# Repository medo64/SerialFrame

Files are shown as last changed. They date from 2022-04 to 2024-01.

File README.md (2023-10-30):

[Isolated UART Framework Expansion Card](https://medo64.com/uartisowork/)
=========================================================================

This Framework laptop expansion card will show up on your system as a serial
device and allow for a fully isolated serial UART communication up to 1 Mbaud
rate.

Please note that this card is not using RS-232 but TTL (either 3.3V or 5V)
voltage levels (depending on the solder-jumper position).

## UART Pinout

To connect to this board, one has to use 3-pin JST XH connector. The following
table represents the pinout, pin 1 being on the left as looking into the
expansion card.

| # | Ref | Description |
|--:|:---:|---|
| 1 | RXD | Receive (TTL: 5V or 3.3V) |
| 2 | GND | Ground connection |
| 3 | TXD | Transmit (TTL: 5V or 3.3V) |

PPS: As power consumption is below 10 mA, wires can be almost any AWG. I would
recommend using 24 AWG wire (0.25 mm²) as they allow for greater compatibility
with other connectors.

## Supported Speeds

This board employs the FT232R as its UART chip, and consequently, it supports
all the baud rates this chip [can handle](https://ftdichip.com/Documents/AppNotes/AN232B-05_BaudRates.pdf)
up to 1 Mbaud which is the limit of isolator chip used. The table below lists
the standard baud rates.

| Baud rate | Actual | Error | Divisor |
|---:|---:|---:|---:|
| 300 | 300 | 0.00% |  10000.000 |
| 600 | 600 | 0.00% | 5000.000 |
| 1,200 | 1,200 | 0.00% | 2500.000 |
| 1,800 | 1,800 | 0.00% | 1666.625 |
| 2,400 | 2,400 | 0.00% | 1250.000 |
| 4,800 | 4,800 | 0.00% | 625.000 |
| 7,200 | 7,201 | 0.01% | 416.625 |
| 9,600 | 9,600 | 0.00% | 312.500 |
| 14,400 | 14,406 | 0.04% | 208.250 |
| 19,200 | 19,200 | 0.00% | 156.250 |
| 28,800 | 28,812 | 0.04% | 104.125 |
| 38,400 | 38,400 | 0.00% | 78.125 |
| 57,600 | 57,692 | 0.16% | 52.000 |
| 115,200 | 115,385 | 0.16% | 26.000 |
| 230,400 | 230,769 | 0.16% | 13.000 |
| 460,800 | 461,538 | 0.16% | 6.500 |
| 921,600 | 923,077 | 0.16% | 3.250 |

---
*You can check my blog and other projects at [www.medo64.com](https://www.medo64.com/electronics/).*

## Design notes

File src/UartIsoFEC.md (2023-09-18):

### UartIsoFEC Parts

|  # | Part | RefDes  | Preferred Part Number |
|---:|---|---|---|
|  2 | C 47pF NP0 16V (0805) | C1-C2 | 399-C0805C470J5GAC7800CT-ND |
|  1 | C 10nF X7R 16V (0805) | C3 | 399-17617-1-ND |
|  7 | C 100nF X7R 16V (0805) | C4-C10  | 478-5311-1-ND |
|  1 | C 4.7uF X5R 16V (0805) | C11 | 1276-1244-1-ND |
|  2 | C 10uF X5R 16V (0805) | C12-C13 | 1276-1096-1-ND |
|  1 | D TVS 5V SM05T1G (SOT23-3) | D1 | SM05T1GOSCT-ND |
|  2 | DS LED (0805) | DS1-DS2 | 475-1415-1-ND |
|  1 | J JST XH Vertical (3w) | J1 | 455-2248-ND |
|  1 | L Ferrite 600R@100Mhz | L1 | 240-2390-1-ND |
|  1 | Q P-MOSFET DMP3099L-13 (SOT23) | Q1 | DMP3099L-13DICT-ND |
|  2 | R 27 1% (0805) | R1-R2 | 738-RMCF0805FT27R0CT-ND |
|  3 | R 1K 0.125W (0805) | R3-R5 | RMCF0805FT1K00CT-ND |
|  1 | R 5.1K 0.125W (0805) | R6 | RMCF0805FT5K10CT-ND |
|  1 | R 10K 0.125W (0805) | R7 | RMCF0805FT10K0CT-ND |
|  1 | R 16.9K 0.125W (0805) | R8 | RMCF0805FT16K9CT-ND |
|  1 | R 30.9K 0.125W (0805) | R9 | RMCF0805FT30K9CT-ND |
|  1 | R 100K 0.125W (0805) | R10 | RMCF0805FT100KCT-ND |
|  1 | U Transciever Uart FT230XS (SSOP-16) | U1 | 768-1154-5-ND |
|  1 | U Isolator+Power 1Mbps 2ch ADUM5211ARSZ (SSOP-20) | U2 | 505-ADUM5211ARSZ-ND |

#### Board Size

| | Dimensions | Area | Thickness |
|---|---|---|---|
| PCB |  24.0 x 27.9 mm | 1.1 in² | 0.8 mm |

#### FTDI Configuration

| Setting | Value  |
|---|---|
| CBUS0 | TXDEN  |
| CBUS1 | RXLED# |
| CBUS2 | TXLED# |
| CBUS3 | PWREN# |

#### Power

| Property | Value  |
|---|---:|
| Voltage  | 5 V |
| Current  | 100 mA |

#### Jumpers

##### 3V3

This jumper has to be bridged for operation in 3.3V. If this jumper is bridged,
5V jumper MUST NOT be bridged too.

##### 5V

This jumper has to be bridged for operation in 5V. If this jumper is bridged,
3.3V jumper MUST NOT be bridged too.

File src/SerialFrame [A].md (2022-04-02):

### SerialFrame Parts

|  # | Part | RefDes  | Preferred Part Number |
|---:|---|---|---|
|  3 | C 100nF X7R 16V (0805) | C1-C3 | 478-5311-1-ND |
|  1 | C 470nF X7R 16V (0805) | C4 | 1276-1199-1-ND |
|  2 | C 10uF X5R 16V (0805) | C5-C6 | 1276-1096-1-ND |
|  2 | DS LED (0805) | DS1-DS2 | 475-1415-1-ND |
|  1 | J JST PH Vertical (5w) | J1 | 455-1707-ND |
|  1 | P USB C, plug, straddle 0.8mm | P1 | WM12855-ND |
|  1 | Q P-MOSFET DMP3099L-13 (SOT23) | Q1 | DMP3099L-13DICT-ND |
|  2 | R 1K 0.125W (0805) | R1-R2 | RMCF0805FT1K00CT-ND |
|  2 | R 5.1K 0.125W (0805) | R3-R4 | RMCF0805FT5K10CT-ND |
|  1 | U MCP2221A (SOIC-14) | U1 | MCP2221A-I/SL-ND |
|  1 | U SI8421AB-D-IS (SOIC-8) | U2 | 336-1755-5-ND |

#### Board Size

| | Dimensions | Area | Thickness |
|---|---|---|---|
| PCB |  24.0 x 27.9 mm | 1.1 in² | 0.8 mm |

#### Power

| Property | Value  |
|---|---:|
| Voltage  | 5 V |
| Current  | 100 mA |

##### Non-Insulated Interface

If one doesn't need insulation (or you really hate your laptop), you can convert
the card into a non-insulated serial interface by soldering 0 Ω resistor on the
bottom (normally unpopulated) and omiting the following components:
* C2, C3
* C5, C6
* DS2
* Q1
* R2
* U2

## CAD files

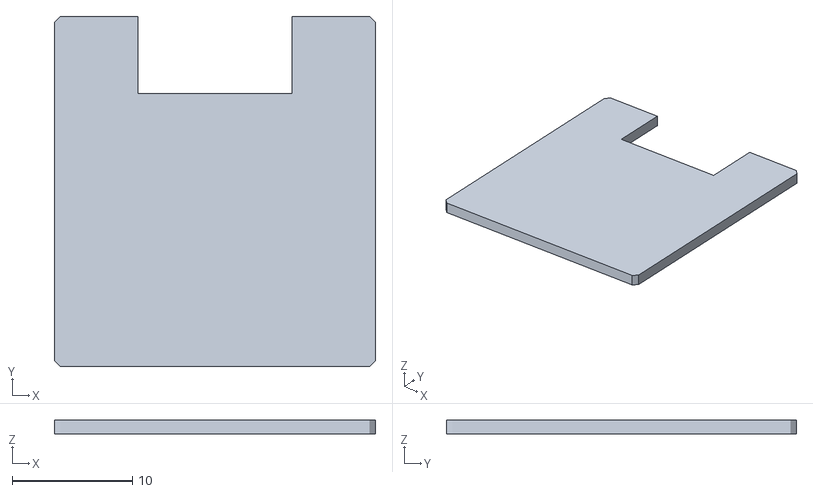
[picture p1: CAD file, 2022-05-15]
src/UartIsoFEC Case Top.stl
26.7 x 29.1 x 1.20

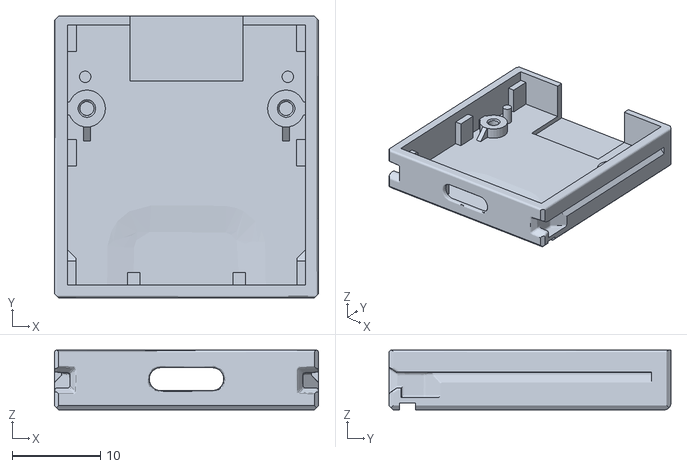
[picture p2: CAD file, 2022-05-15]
src/UartIsoFEC Case Base.stl
30.0 x 32.0 x 6.80

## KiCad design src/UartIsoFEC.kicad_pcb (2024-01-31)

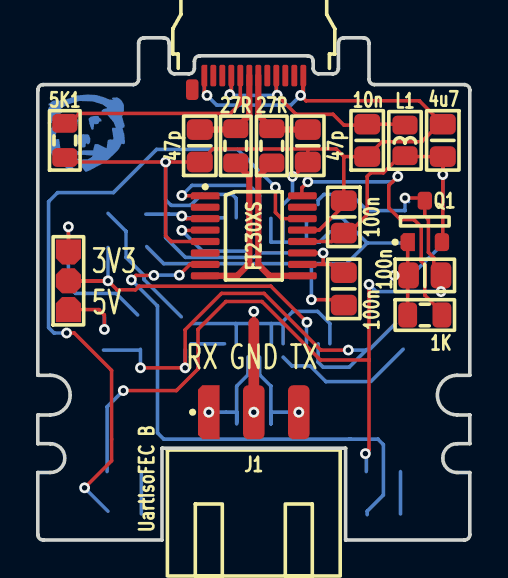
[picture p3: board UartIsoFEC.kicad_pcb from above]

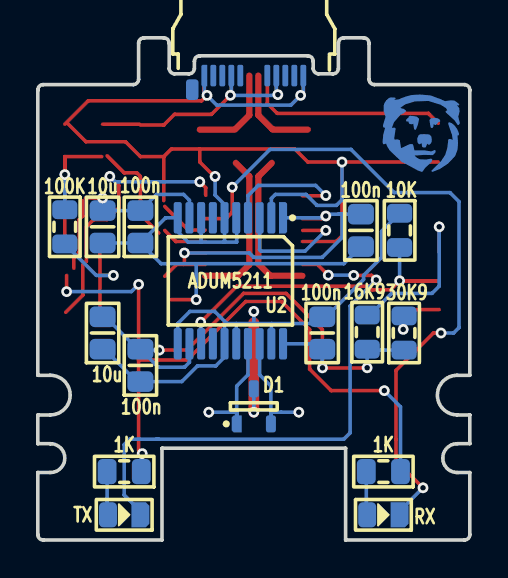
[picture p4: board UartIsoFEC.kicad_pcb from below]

Board: 2 copper layers, 24.0 x 27.9 mm, 34 parts (17 on the bottom side), 25 nets.

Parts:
C1, C2: 47p; C (0805)
C3: 10n; C (0805)
C4, C5, C6, C7, C8, C9, C10: 100n; C (0805)
C11: 4u7; C (0805)
C12, C13: 10u; C (0805)
D1: SM05T1G; D TVS SM05T1G (SOT23-3)
DS1: RX; DS (0805)
DS2: TX; DS (0805)
ICON: Medo64; ICON Medo64
J1: B3B-XH-A; J JST XH Edge [UART] (3w)
JP1: Jumper; JP Dual (1205)
L1: 600R; L (0805)
P1: 105444-0001; P USB C 3.2 Edge (24w)
Q1: DMP3099L-13; Q MOSFET-P (SOT23-3)
R1, R2: 27R; R (0805)
R3, R4, R5: 1K; R (0805)
R6: 5K1; R (0805)
R7: 10K; R (0805)
R8: 16K9; R (0805)
R9: 30K9; R (0805)
R10: 100K; R (0805)
U1: FT230XS; U Transciever UART FT230XS (SSOP-16)
U2: ADUM5211; U Isolator+Power ADUM5211ARSZ (SSOP-20)

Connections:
3V3: C5.2, C8.2, U1.3, U1.10, U1.11, U2.1
5V: C4.2, C11.2, L1.1, Q1.2, R10.1, U1.12
5V_SWITCHED: C6.2, C7.2, C12.2, Q1.3, R3.1, R4.1, U2.9
GND: C1.1, C2.1, C3.1, C4.1, C5.1, C7.1, C8.1, C11.1, C12.1, P1.A1, P1.A12, P1.B01, P1.B12, R6.1, U1.5, U1.13, U2.2, U2.5, U2.6, U2.8, U2.10
ISO_GND: C9.1, C10.1, C13.1, D1.3, J1.2, R7.1, U2.11, U2.15, U2.16, U2.19
ISO_RX: D1.2, J1.1, U2.18
ISO_TX: D1.1, J1.3, U2.17
ISO_V+: C9.2, C10.2, C13.2, R8.1, R9.1, U2.12, U2.20
ISO_V_SELECT: JP1.2, R7.2, U2.13
ISO_V_SELECT_3V3: JP1.3, R8.2
ISO_V_SELECT_5V: JP1.1, R9.2
LED_RX: DS1.1, U1.14
LED_RX': DS1.2, R3.2
LED_TX: DS2.1, U1.7
LED_TX': DS2.2, R4.2
PWREN#: R5.2, U1.16
PWREN#': C6.1, Q1.1, R5.1, R10.2
RX: U1.4, U2.3
TX: U1.1, U2.4
USB_CC: P1.A5, R6.2
USB_DM: C2.2, P1.A7, R2.2
USB_DM': R2.1, U1.9
USB_DP: C1.2, P1.A6, R1.2
USB_DP': R1.1, U1.8
USB_V+: C3.2, L1.2, P1.A4, P1.A9, P1.B04, P1.B09

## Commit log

2022-04-02 Added reverse voltage protection diode
2022-04-02 LED on by default
2022-04-02 Using MOSFET for reverse protection
2022-04-02 Updated MOSFET
2022-04-02 Added wiring text file
2022-04-18 Moving LEDs a bit
2022-05-07 Removed extra CC2 resistor
2022-05-09 Changed connector to XH variant
2022-05-09 Added case STLs
    [UartIsoWork [A] CaseBase.stl, UartIsoWork [A] CaseTop.stl]
2022-05-15 Updated case STLs
    [UartIsoWork [A] CaseBase.stl, UartIsoWork [A] CaseTop.stl]
2023-09-17 Initial layout
    [UartIsoFEC.kicad_pcb]
2023-09-18 New revision using FT260X
    [UartIsoFEC Case Base.stl, UartIsoFEC Case Top.stl, UartIsoFEC.kicad_pcb]
2023-09-18 Added protection diode
    [UartIsoFEC.kicad_pcb]
2023-10-10 Larger silkscreen markings
    [UartIsoFEC.kicad_pcb]
2023-10-25 Updated footprints
    [UartIsoFEC.kicad_pcb]
2023-10-30 Rotated CC resistor
    [UartIsoFEC.kicad_pcb]
2023-10-30 Increased drive current
2023-11-03 Updated net names
    [UartIsoFEC.kicad_pcb]
2023-11-04 Added RTS/CTS loopback
    [UartIsoFEC.kicad_pcb]
2023-11-13 Moved LEDs to bottom
    [UartIsoFEC.kicad_pcb]
2023-12-26 Refactored LED control
    [UartIsoFEC.kicad_pcb]
2023-12-26 Removed internal RTS/CTS connection
    [UartIsoFEC.kicad_pcb]
2023-12-26 Added missing PWREN pullup resistor
    [UartIsoFEC.kicad_pcb]
2023-12-30 Minor cleanup and expanding soldermask
    [UartIsoFEC.kicad_pcb]
2024-01-31 Moved LEDs
    [UartIsoFEC.kicad_pcb]
2024-01-31 Moved board RefDes to top
    [UartIsoFEC.kicad_pcb]
